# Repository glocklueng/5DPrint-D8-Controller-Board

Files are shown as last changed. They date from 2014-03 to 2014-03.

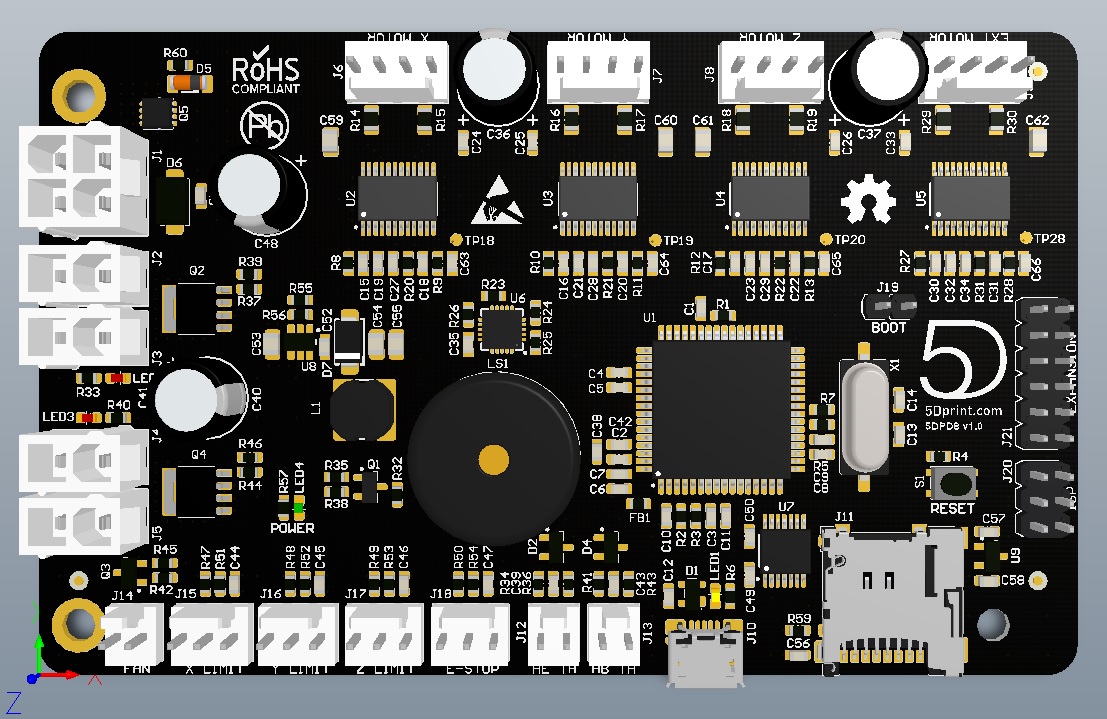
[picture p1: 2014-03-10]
5DPD8_v1.0_OS.jpg

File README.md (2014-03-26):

5DPrint D8 Controller
=====================
The 5DPrint D8 is an open source 3D printer controller, designed for controlling the [MakiBox A6](https://store.makibox.com/) and other RepRap type/small consumer grade 3D printers.

Inspired by the Printrboard Rev.B and its predecessors, the D8 was redesigned from the ground up in order to improve upon the overall functionality and also eliminate some of the shortcomings inherant to these previous designs.

Firmware
--------
The D8 runs on the [5DPrint Firmware](https://bitbucket.org/makible/5dprint-firmware), which is a fork of Sprinter.

License
-------
The D8 design is licensed under [Creative Commons Attribution-ShareAlike 4.0 International (CC BY-SA 4.0)](https://creativecommons.org/licenses/by-sa/4.0/).

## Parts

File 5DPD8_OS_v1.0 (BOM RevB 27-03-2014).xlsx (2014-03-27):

Project: 5DPD8_OS
Board Rev: 1.0
BOM Rev.: B
Author: Martyn Kay
Date: 27th March 2014
Type | Designator | Comment | Description | Quantity | Manufacturer | MPN
Capacitor | C1, C8, C38, C42, C44, C45, C46, C47, C63, C64, C65, C66 | 10nF | CAP CER 10000PF 50V 10% X7R 0603 | 12 | Yageo | CC0603KPX7R9BB103
 | C2, C4, C7, C9, C10, C11, C15, C16, C17, C19, C21, C23, C24, C25, C26, C30, C32, C33, C35, C39, C41, C43, C49, C50, C51, C56 | 0.1µF | CAP CER 0.1UF 50V 10% X7R 0603 | 26 | Yageo | CC0603KRX7R9BB104
 | C3, C57 | 1.0µF | CAP CER 1UF 10V 10% X7R 0603 | 2 | Taiyo Yuden | LMK107B7105KA-T
 | C5, C6, C12 | 10µF | CAP CER 10UF 10V 10% X5R 0603 | 3 | TDK Corporation | C1608X5R1A106K080AC
 | C13, C14 | 27pF | CAP CER 27PF 50V 1% NP0 0603 | 2 | Murata Electronics North America | GRM1885C1H270FA01D
 | C18, C20, C22, C27, C28, C29, C31, C34, C52 | 0.22µF | CAP CER 0.22UF 50V 10% X7R 0603 | 9 | TDK Corporation | C1608X7R1H224K080AB
 | C36, C37, C40, C48 | 220µF | CAP ALUM 220UF 35V 20% RADIAL | 4 | Rubycon | 35ZLH220MEFC8X11.5
 | C53, C59, C60, C61, C62 | 2.2µF | CAP CER 2.2UF 50V 10% X7R 0805 | 5 | Taiyo Yuden | UMK212BB7225KG-T
 | C54, C55 | 22µF | CAP CER 22UF 10V 10% X5R 0805 | 2 | TDK Corporation | C2012X5R1A226K125AB
 | C58 | 4.7µF | CAP CER 4.7UF 6.3V 10% X5R 0603 | 1 | Taiyo Yuden | JMK107BJ475KA-T
Diode | D1 | PRTR5V0U2AX,235 | DIODE ESD PROTECT 5.5V SOT143B | 1 | NXP Semiconductors | PRTR5V0U2AX,235
 | D2, D4 | BAT54S,215 | DIODE SCHOTTKY 30V 200MA TO236AB | 2 | NXP Semiconductors | BAT54S,215
 | D5 | BZV55-C10,115 | DIODE ZENER 10V 500MW LLDS | 1 | NXP Semiconductors | BZV55-C10,115
 | D6 | SMAJ24CA | DIODE TVS 24V 400W BIDIR 5% SMA | 1 | Littelfuse Inc | SMAJ24CA
 | D7 | B140-13-F | DIODE SCHOTTKY 40V 1A SMA | 1 | Diodes Inc | B140-13-F
Ferrite | FB1 | MMZ1608R301A | FERRITE CHIP 300 OHM 500MA 0603 | 1 | TDK Corporation | MMZ1608R301A
Connector | J1 | 0039281043 | CONN HEADER 4POS 4.2MM VERT TIN | 1 | Molex Inc | 0039281043
 | J2, J3, J4, J5 | 0039281023 | CONN HEADER 2POS 4.2MM VERT TIN | 4 | Molex Inc | 0039281023
 | J6, J7, J8, J9 | 0022272041 | CONN HEADER 4POS .100 VERT TIN | 4 | Molex Inc | 0022272041
 | J10 | 10103594-0001LF | CONN RCPT STD MICRO USB TYPE B | 1 | FCI | 10103594-0001LF
 | J11 | 5031821853 | CONN MICRO SD MEMORY CARD 8CKT | 1 | Molex Inc | 5031821853
 | J12, J13, J14 | 0022272021 | CONN HEADER 2POS .100 VERT TIN | 3 | Molex Inc | 0022272021
 | J15, J16, J17, J18 | 0022272031 | CONN HEADER 3POS .100 VERT TIN | 4 | Molex Inc | 0022272031
 | J19 | 67996-402HLF | CONN HEADER 2POS .100 STR TIN | 1 | FCI | 67996-402HLF
 | J20 | 67996-406HLF | CONN HEADER 6POS .100 STR TIN | 1 | FCI | 67996-406HLF
 | J21 | 67996-412HLF | CONN HEADER 12POS .100 STR TIN | 1 | FCI | 67996-412HLF
Inductor | L1 | SRN6045-220M | INDUCTOR POWER SHIELD 22µH SMD | 1 | Bourns Inc. | SRN6045-220M
LED | LED1 | HSMY-C190 | LED 589NM YELLOW DIFF 0603 SMD | 1 | Avago Technologies US Inc. | HSMY-C190
 | LED2, LED3 | HSMH-C190 | LED 660NM RED DIFF 0603 SMD | 2 | Avago Technologies US Inc. | HSMH-C190
 | LED4 | HSMG-C190 | LED 570NM GREEN DIFF 0603 SMD | 1 | Avago Technologies US Inc. | HSMG-C190
Buzzer | LS1 | PS1740P02E | BUZZER PIEZO 4KHZ 17MM PC MOUNT | 1 | TDK Corporation | PS1740P02E
Transistor | Q1 | 2N7002,215 | MOSFET N-CH 60V 300MA SOT-23 | 1 | NXP Semiconductors | 2N7002,215
 | Q2, Q4 | PSMN9R5-30YLC,115 | MOSFET N-CH 30V 44A LL LFPAK | 2 | NXP Semiconductors | PSMN9R5-30YLC,115
 | Q3 | IRLML2060TRPBF | MOSFET N-CH 60V 1.2A SOT23-3 | 1 | International Rectifier | IRLML2060TRPBF
 | Q5 | SIS427EDN-T1-GE3 | MOSFET P-CHAN 30V 1212-8 | 1 | Vishay Siliconix | SIS427EDN-T1-GE3
Resistor | R1, R4, R8, R9, R10, R11, R12, R13, R26, R27, R28, R32, R38, R39, R45, R46, R47, R48, R49, R50, R59, R60 | 10k | RES 10K OHM 1/10W 5% 0603 SMD | 22 | Yageo | RC0603JR-0710KL
 | R2, R3, R35, R37, R42, R44 | 22R | RES 22.0 OHM 1/10W 1% 0603 SMD | 6 | Yageo | RC0603FR-0722RL
 | R5, R20, R21, R22, R31 | 0R | RES ZERO OHM 1/10W JUMP 0603 SMD | 5 | Yageo | RC0603JR-070RL
 | R6, R51, R52, R53, R54, R56, R57 | 1k | RES 1.00K OHM 1/10W 1% 0603 SMD | 7 | Yageo | RC0603FR-071KL
 | R14, R15, R16, R17, R18, R19, R29, R30 | 0R1 | RES 0.100 OHM 0.5W 1% 0805 | 8 | Susumu | KRL1220E-M-R100-F-T5
 | R23, R34, R41 | 4k7 | RES 4.70K OHM 1/10W 1% 0603 SMD | 3 | Yageo | RC0603FR-074K7L
 | R24, R25 | 2k2 | RES 2.2K OHM 1/10W 5% 0603 SMD | 2 | Yageo | RC0603JR-072K2L
 | R33, R36, R40, R43 | 2k4 | RES 2.4K OHM 1/4W 5% 0603 SMD | 4 | Rohm Semiconductor | ESR03EZPJ242
 | R55 | 5k6 | RES 5.60K OHM 1/10W 1% 0603 SMD | 1 | Yageo | RC0603FR-075K6L
Switch | S1 | PTS810 SJK 250 SMTR LFS | SWITCH TACTILE SPST-NO 0.05A 16V | 1 | C&K Components | PTS810 SJK 250 SMTR LFS
IC | U1 | AT90USB1286-AUR | IC MCU 8BIT 128KB FLASH 64TQFP | 1 | Atmel | AT90USB1286-AUR
 | U2, U3, U4, U5 | A4982SLPTR-T | IC MOTOR DRIVER PAR 24TSSOP | 4 | Allegro MicroSystems, LLC | A4982SLPTR-T
 | U6 | MCP4451-103E/ML | IC POT 10K QUAD 8BIT 20QFN | 1 | Microchip Technology | MCP4451-103E/ML
 | U7 | TXB0104PWRG4 | IC VOLT-LEVEL TRANSLATOR 14TSSOP | 1 | Texas Instruments | TXB0104PWRG4
 | U8 | LMR14206XMKX/NOPB | IC REG BUCK ADJ 0.6A 6TSOT | 1 | Texas Instruments | LMR14206XMKX/NOPB
 | U9 | AP7313-33SAG-7 | IC REG LDO 3.3V 0.15A SOT23-3 | 1 | Diodes Inc | AP7313-33SAG-7
Crystal | X1 | ABLS-16.000MHZ-K4T | CRYSTAL 16MHZ 18PF SMD | 1 | Abracon Corporation | ABLS-16.000MHZ-K4T

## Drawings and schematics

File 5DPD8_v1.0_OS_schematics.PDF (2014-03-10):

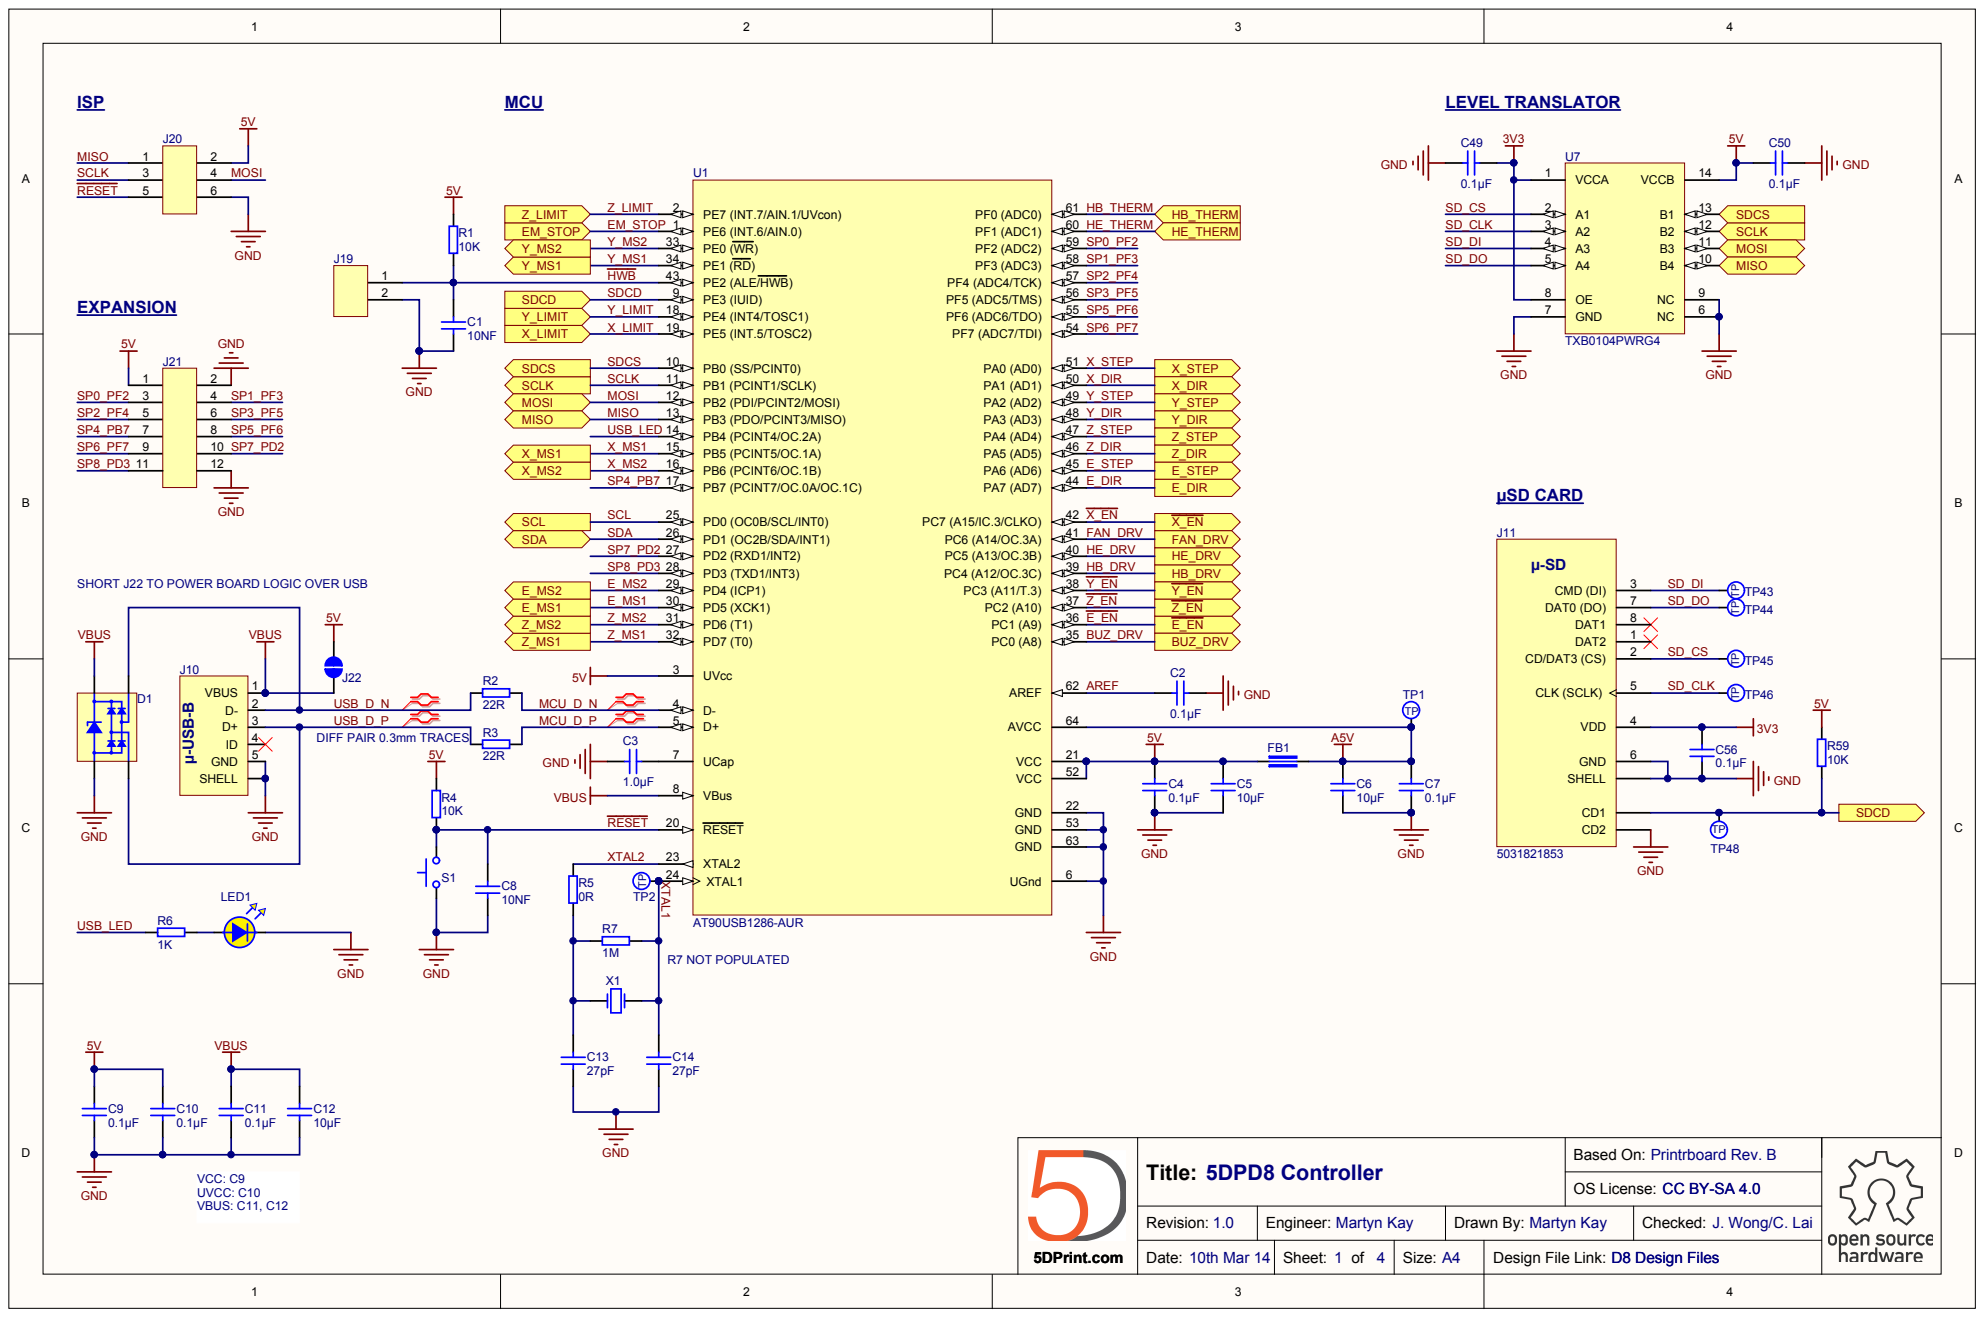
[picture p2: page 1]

SHORT J22 TO POWER BOARD LOGIC OVER USB

2 | | USB_D_N
D+ | 3 USB_D_P MCU_D_P 5

XTAL2 | | 6

XTAL1 24

Based On: Printrboard Rev. B

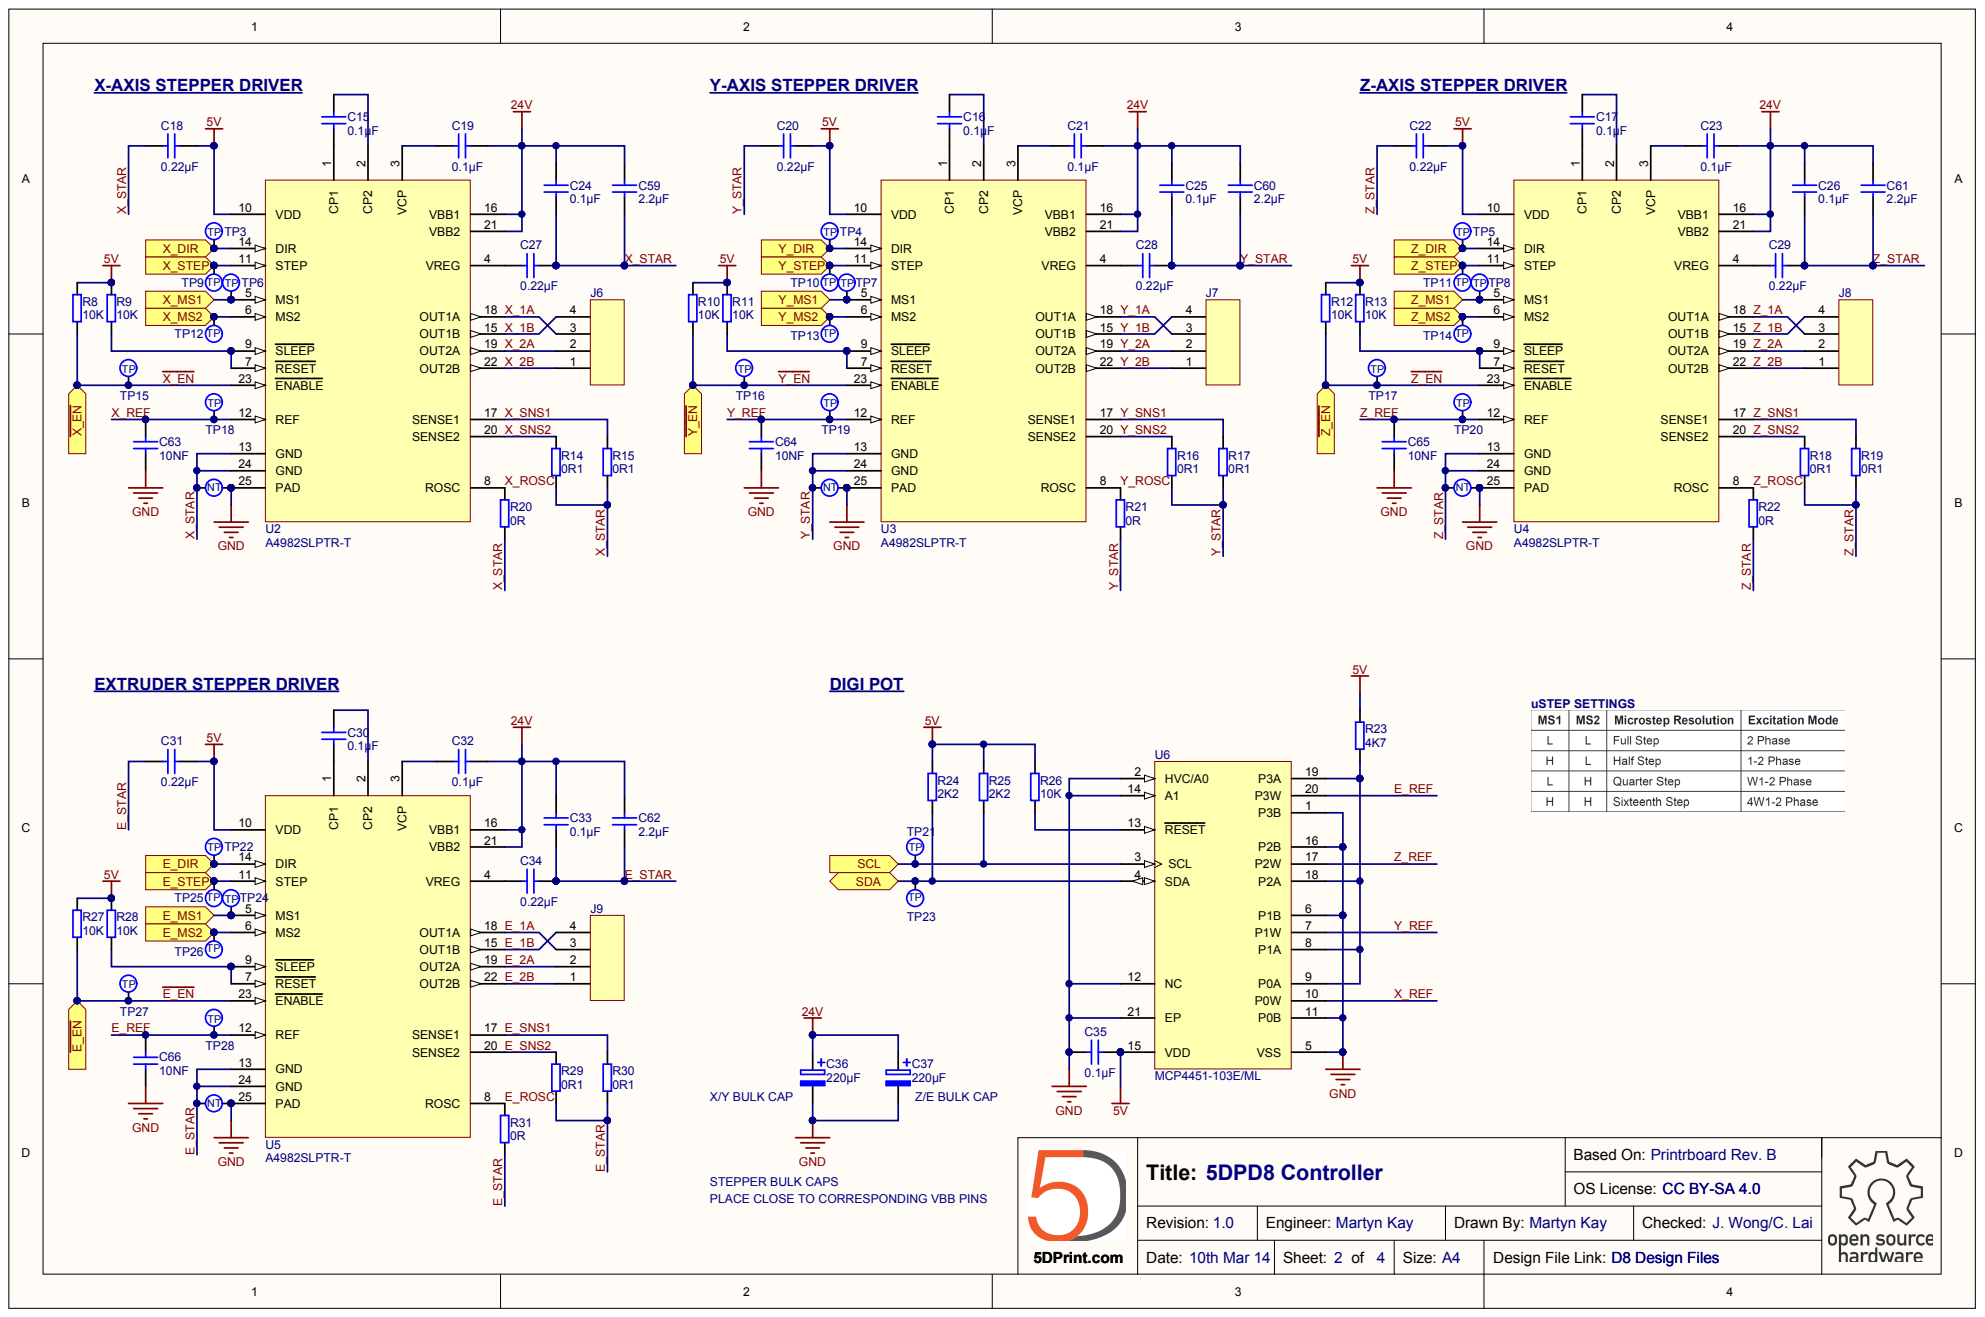
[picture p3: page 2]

C35 | VDD 15

PAD 25 GND 24 GND 13

Based On: Printrboard Rev. B

STEPPER BULK CAPS
PLACE CLOSE TO CORRESPONDING VBB PINS

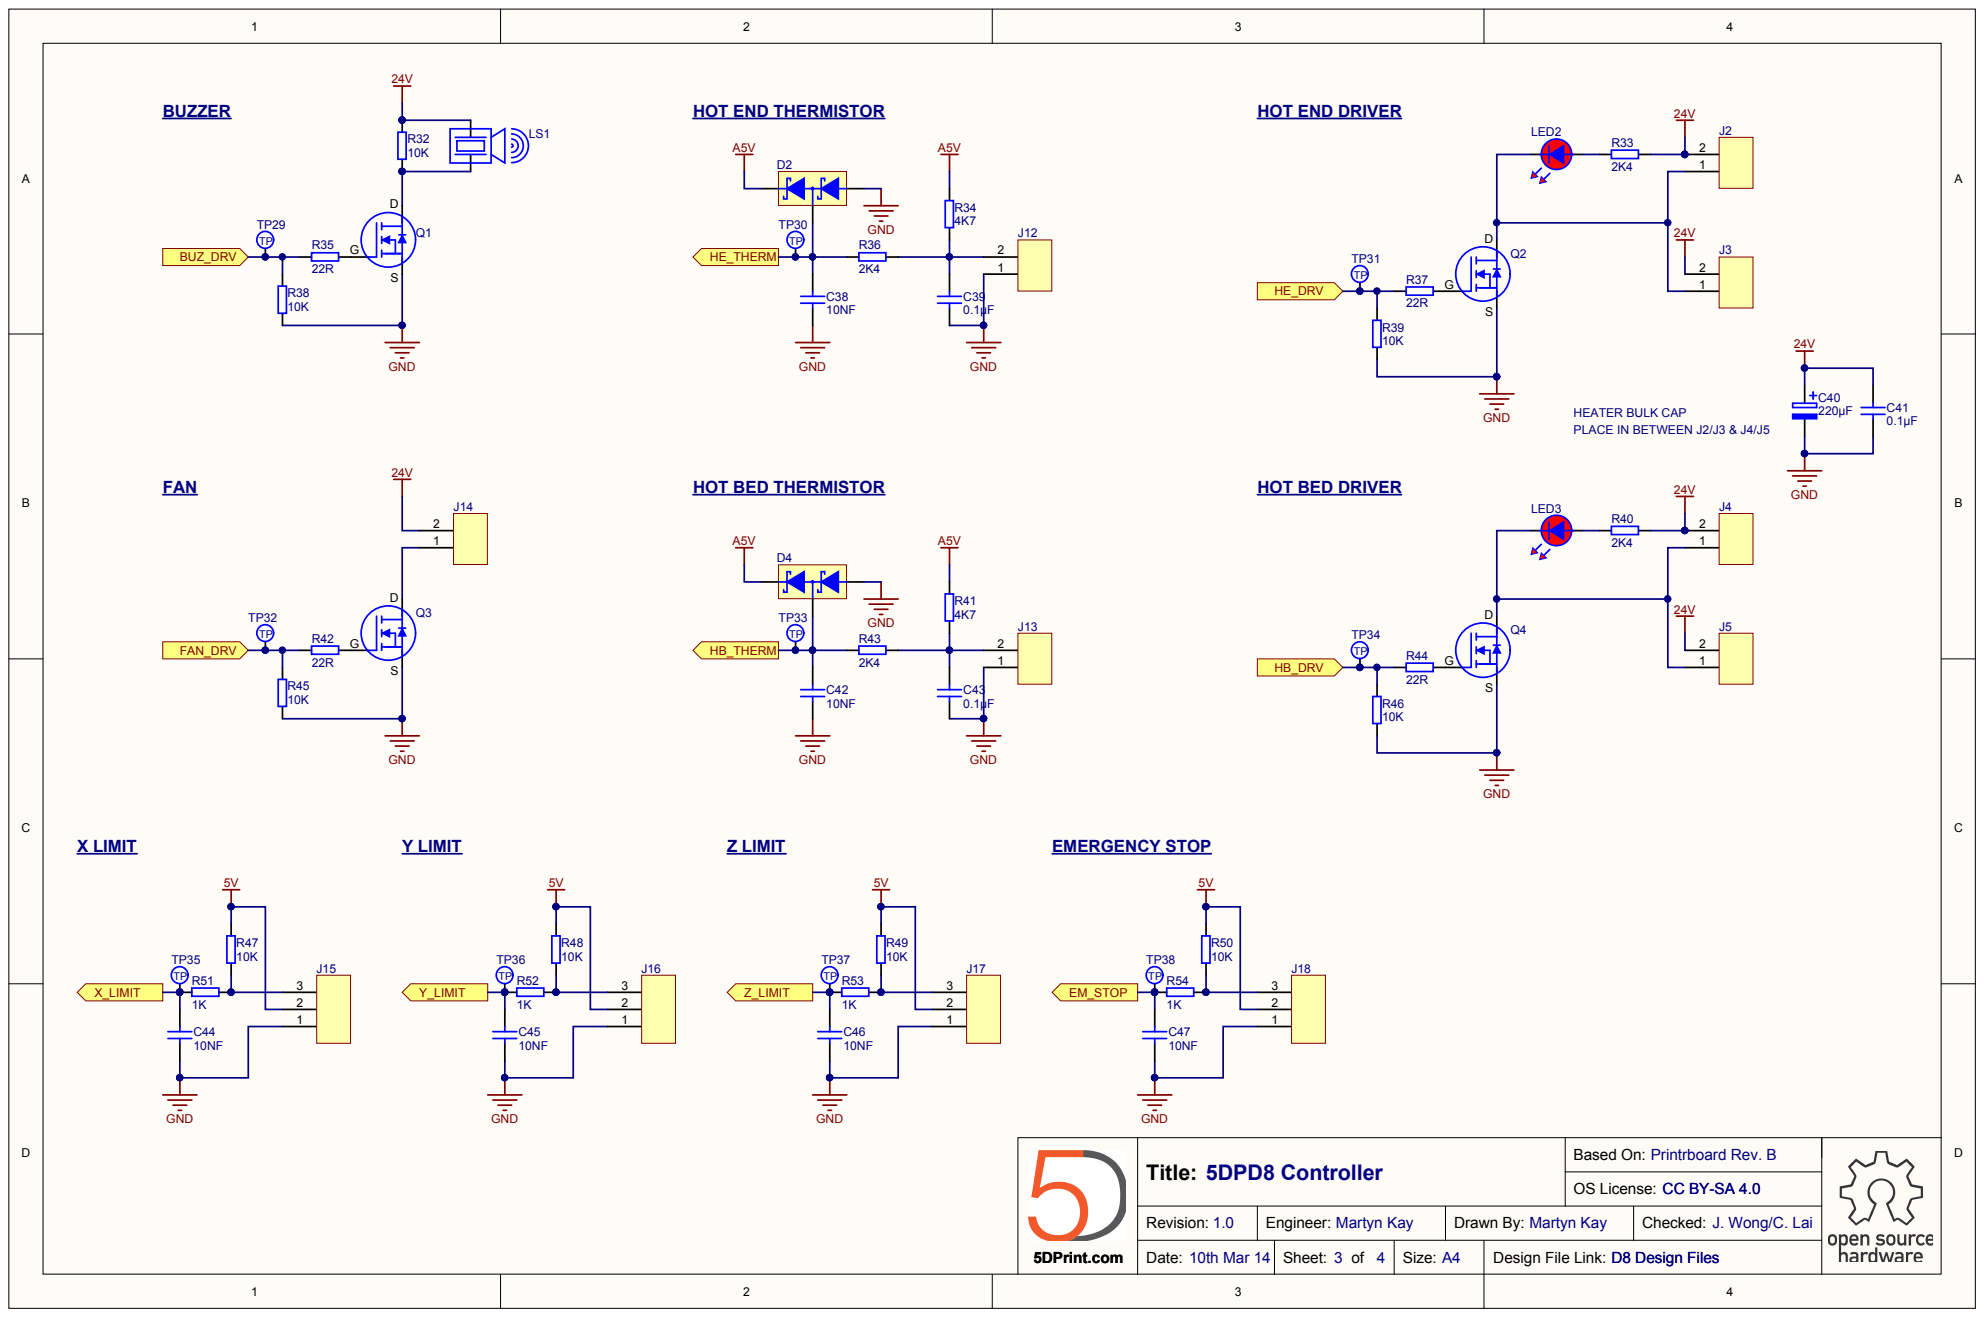
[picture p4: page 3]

Based On: Printrboard Rev. B

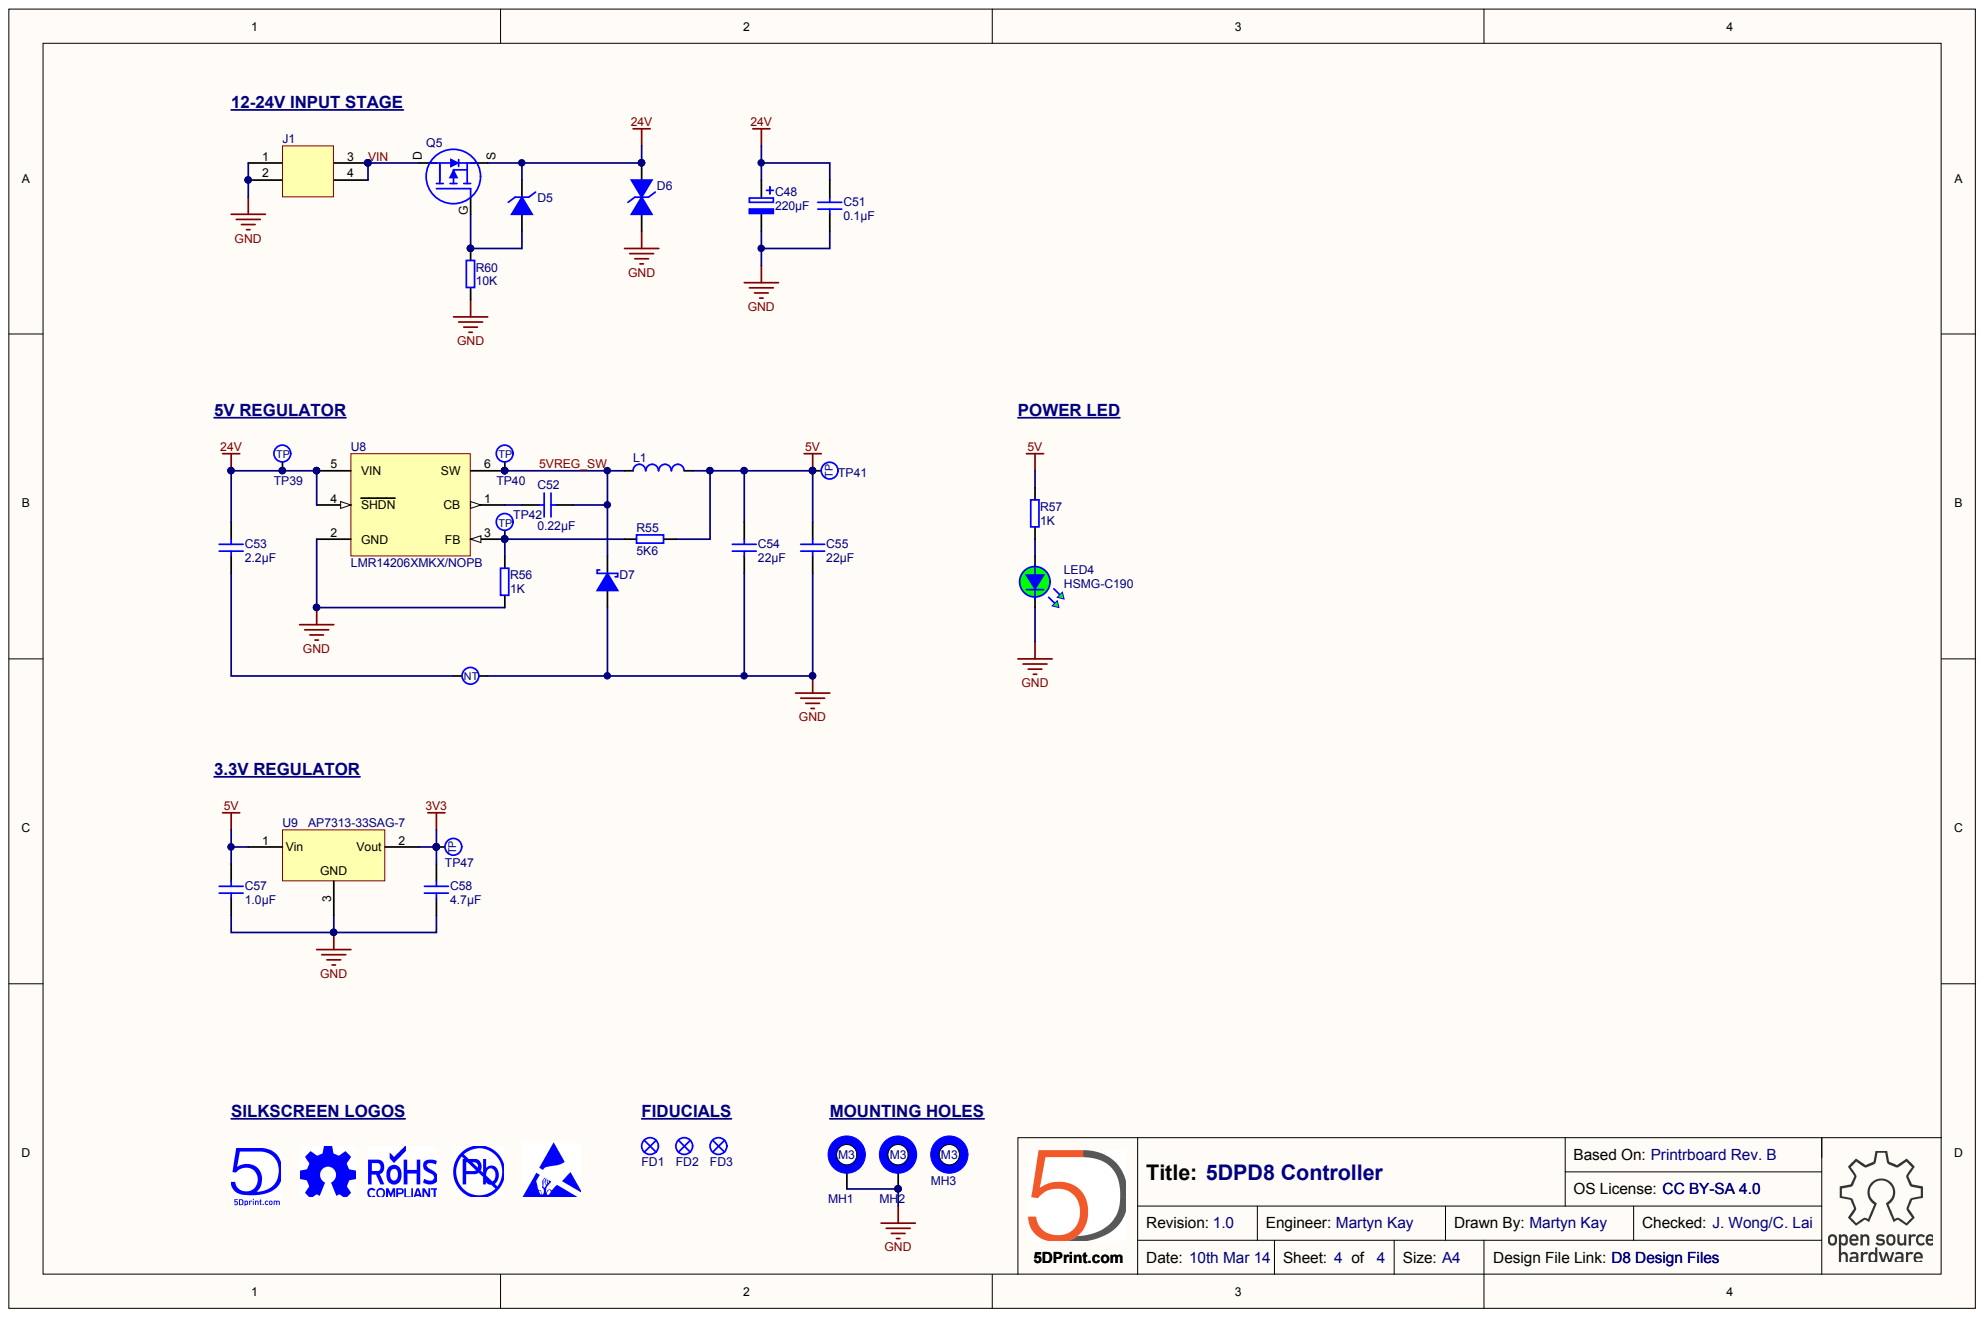
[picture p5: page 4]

TP39 | SHDN 4 | TP40 C52

GND 2 | TPTP42 0.22µF

Based On: Printrboard Rev. B

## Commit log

2014-03-10 5DPD8 v1.0 OS design files
    [5DPD8_OS.PrjPcb, 5DPD8_OS_v1.0 (BOM RevA 10-03-2014).xlsx, 5DPD8_v1.0_OS_Sheet1.SchDoc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]
2014-03-10 Fixed incorrect numbering of total schematic sheets and added smart PDF of schematics.
    [5DPD8_v1.0_OS_Sheet1.SchDoc, 5DPD8_v1.0_OS_Sheet2.SchDoc, 5DPD8_v1.0_OS_Sheet3.SchDoc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]
2014-03-27 BOM RevB - Corrected incorrect quantity value for C53, C59, C60, C61, C62
    [5DPD8_OS_v1.0 (BOM RevB 27-03-2014).xlsx]
2014-03-27 Removed BOM RevA
    [5DPD8_OS_v1.0 (BOM RevA 10-03-2014).xlsx]
2014-04-14 Updated THT headers and stepper SNS resistor footprints with correct courtyard sizes
    [5DPD8_OS.PrjPcb, 5DPD8_v1.0_OS_Sheet2.SchDoc]
2014-04-14 First commit of gerber and NC drill files
